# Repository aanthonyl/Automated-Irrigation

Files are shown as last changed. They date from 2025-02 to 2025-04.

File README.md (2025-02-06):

# Automated Crop Irrigation and Monitoring

This is the repository that holds the code that runs on each microcontroller.

This project focuses on creating an automated irrigation system using moisture sensors and other sensors to control a solenoid valve that controls irrigation.

## Setup
[Follow this link to initialize a new microcontroler for circuitpython](https://learn.adafruit.com/welcome-to-circuitpython/installing-circuitpython)

[More Info](https://docs.google.com/document/d/19N1eyoPY3S1OBYUITAjoR1po-gBfBbgVvcPOLOSFNLY/edit?usp=sharing)

### Libraries
[Most Libraries needed for our project](https://circuitpython.org/libraries)

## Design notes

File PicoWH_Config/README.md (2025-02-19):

This folder will contain all the configuration files necessary to recreate a new Raspberry Pi Pico WH to be compatible with this project.

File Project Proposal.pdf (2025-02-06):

# Automated Crop Irrigation and Monitoring

## AquaByte

Megan Arbuckle- Developer

Jillian Armstrong- Developer

Daniel Gruen- IoT Software & Network Engineer

Anthony Liao- Project Manager

Advisor: Carsten Thue-Bludworth, carstentb@ufl.edu

02/02/2025

## Abstract

On the Field and Fork Farm, crops are irrigated through a series of timers that

periodically send water to different fields for various set times. This system works well,

however, it is not very responsive to changes such as heavy rain, leaks, or other changes that

would need to adjust the watering schedule. Since it follows a set schedule, it can be an

inefficient usage of water since it cannot determine when it is best to water, but rather constantly

waters to make sure plants have the water they need. It also must be managed on site, so

someone must be on the farm physically to change the watering schedule or notice leaks. This

project aims to develop an automated irrigation system that leverages different sensors, including

soil moisture and sunlight intensity sensors, that are periodically measured by a microcontroller

and sent wirelessly to an online dashboard. These live readings and values will be used to

dynamically determine when plants need watering to conserve water and remove the need for a

person to manage it day to day. The online dashboard will allow a user to view the data collected

from each microcontroller and remotely manage the irrigation to turn it on or off. While other

solutions exist for this issue, our goal is to use cheaply available microcontrollers and sensors to

keep costs low for the Field and Fork Farm. Overall, this automated irrigation controller

simplifies farm management by reducing the daily workload required for irrigation, allowing

farmers to focus on other essential tasks.

## Table of Contents

Cover | 1
Abstract | 2
Table of Contents | 3
Team Contract | 4
Introduction and Motivation | 7
Literature Survey | 9
Proposed Works | 11
User Stories | 13
Project Plan | 14
Github | 16
References | 17
Advisor Signature | 18

## Team Contract

Overall objectives: What the team is trying to achieve?

- Our objective is to create an IoT system for the Field and Fork Farm that collects data on

various variables including moisture level, temperature, and light levels. Using this

information we want to be able to control irrigation schedules and be able to manage

irrigation remotely through an online dashboard.

Individual responsibilities: What each team member is expected to do?

- Communicate clearly with other members.
- Complete their portion of the work and tasks.
- Work at least three hours every week.

Values and Agreement Statements: Team agreements are written by everyone and they help

define comfortable working parameters for everyone.

- We will come to all meetings and will let each other know if a meeting time does not

work.

- We will do our work efficiently and effectively.
- We will communicate with each other about the project and about deadlines.
- We will ask for help from each other or our advisor if needed.

Software Configuration Management Protocol: refers to a set of defined procedures and

standards used to track, control, and manage changes made to the software system to ensure consistency and quality of all modifications, management of merge conflicts, and version

control.

- We are using Github for version control in our project. Due to the nature of our project,

each of us will be working with separate code bases in the same repository, so we will all

push to the main branch in separate folders that we PR to have each other look over.

Meeting times: When the team will meet outside the meeting with the advisor?

- Our team will meet weekly and the days will change depending on availability. We will

fill out a When2meet to determine the best possible day and time.

Meeting times with advisor: Frequency and Order of Meeting Facilitator (Everyone is required to

lead/facilitate at least 1 meeting with the advisor; everyone must be present for all meetings with

your advisor).

- We plan on meeting our advisor every other week during the duration of our project.

Communication: How team members will communicate with each other; what platforms?

- We will use discord/text for communicating when not meeting in person.

Conflict resolution protocol: How the team will solve problems?

- Our team will solve problems by discussing any issues with each other and working out a

solution together.

- If needed, we will discuss it with our advisor.

Consequences: What happens if someone violates the agreement?

- If someone violates the agreement, we will first try discussing the issue with a teammate

in violation of the agreement and if not resolvable, we will bring it to the attention of the

advisor and decide on the correct course of action.

Signatures

Daniel Gruen 1/18/25

Megan Arbuckle 1/18/25

Anthony Liao 1/18/25

Jillian Armstrong 1/18/25

## Introduction and Motivation

Water management in agriculture is a significant challenge, with inefficient irrigation

methods leading to water waste, increased costs, or inconsistent crop yields. Farmers must

manually monitor weather and adjust irrigation schedules, which is time-consuming and prone to

human error. Additionally, climate variability makes it difficult to predict the optimal watering

times. In the United States, agricultural irrigation accounted for 42% of the nation’s total

freshwater usage in 2015 (Dieter et al., 2018). As agricultural irrigation is a significant usage of

water, in places where water is scarce, such as California, or places where the soil is more sandy

and does not hold onto water, such as Florida, it is imperative that water is managed carefully.

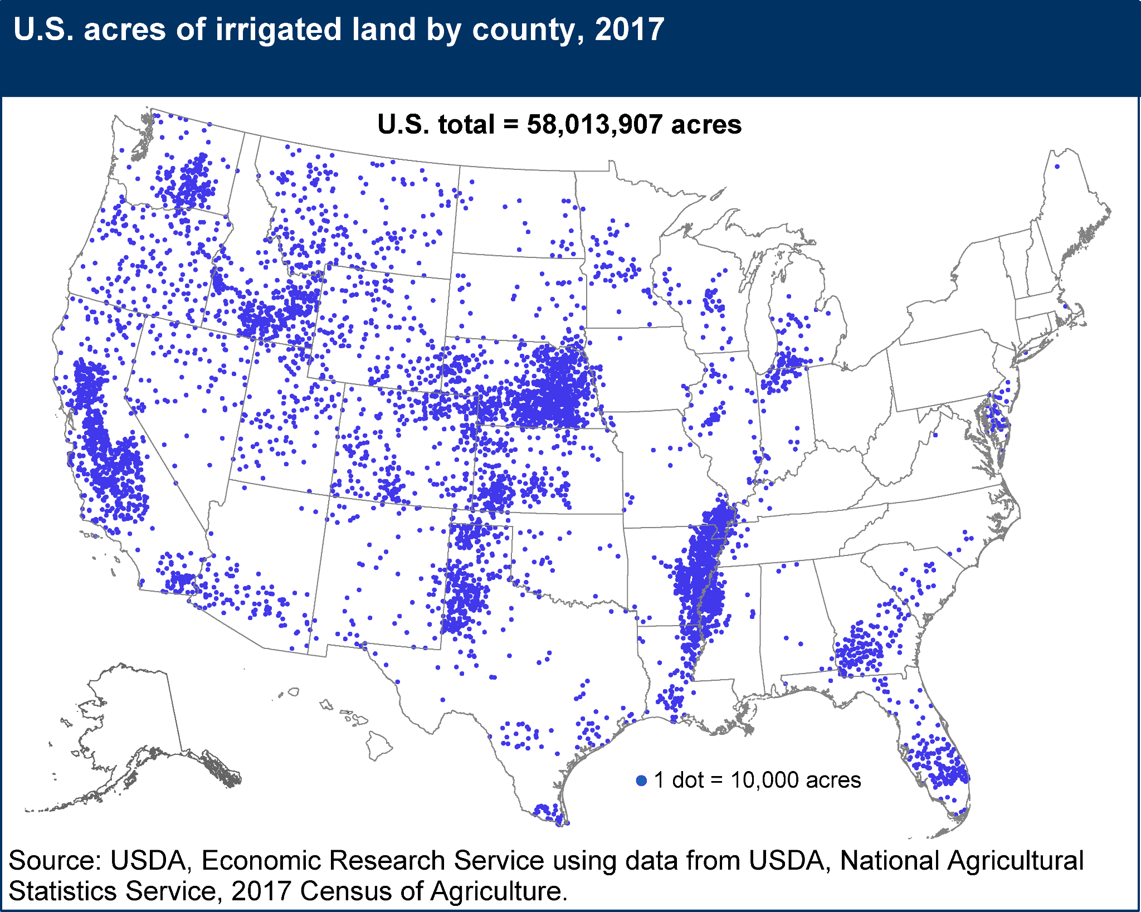
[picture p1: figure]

To help manage water usage on irrigated agricultural land, our project proposes creating

smart systems that optimize water usage by leveraging technology such as soil moisture sensors,

weather data, and automated valves to ensure crops receive the right amount of water at the right

time. This not only conserves water but also reduces labor costs and improves crop health. With many low cost sensors and microcontrollers readily available in the market, creating a scalable

and affordable system is very feasible.

Our project focuses on the Field and Fork Farm at the University of Florida, which

currently uses traditional irrigation systems which utilize timers to control watering schedules.

We propose an intelligent, sensor-based irrigation system that automatically adjusts water

distribution based on real-time environmental conditions. This will be accomplished by utilizing

moisture, light, and temperature sensors to monitor the environment, and a microcontroller to

utilize this data and control irrigation via solenoids. This microcontroller will communicate with

an online dashboard as well for ease of access to control irrigation and monitor data. The impact

of this project will be in water conservation, simplified farm management, and improving

watering consistency leading to better crop yield. By streamlining irrigation management, a

farmer’s time and energy can go into other aspects of the farm.

## Literature Survey

Literature Survey 1:

The first piece of research we found discusses the importance of soil moisture on

irrigation and the yield of crops, and how soil moisture sensor technology can help agricultural

performance (Limin Yu, et al.). The researchers discuss how they analyzed and compared

different measurement methods and how these sensors can be improved for future development.

They were able to test different kinds of moisture sensors and report the main advantages and

takeaways of how each one performed. During their testing, they determined that different

environmental factors, such as temperature, affected the measurements of the soil moisture

sensors, which is similar to what we will be testing and measuring. While our project will be on a

much smaller scale, it can also be used to determine more about the improvement of soil

moisture sensors and how they can be used in larger scale applications.

Literature Survey 2:

This idea was also carried out on farms in Indonesia by some researchers from the

Institute of Informatics and Computing Energy at Universiti Tenaga Nasional, the University

Hassan II of Casablanca, and the Department of Electrical Engineering at Gujarat Technological

University (Ipin Prasojo, et al.). They aimed to improve the efficiency of the farms because the

farmers didn’t often grow anything in dry seasons due to concerns about watering issues. In their

research, they designed a microcontroller chip that uses a moisture sensor in the soil to determine

whether the crops should be watered at a given time. The microchip would activate a solenoid

when water was needed in the soil, and would release a different amount of water depending on

how much moisture is already in the soil. It was found to be beneficial to the crop growth on the farms it was tested on, since the farmers did not have to water the soil themselves and the plants

didn’t suffer due to either over- or under-watering.

Literature Survey 3:

A research team from the G.M. Vedak Institute of Technology in India (Yadav et al.,

2021) developed a smart irrigation system to aid small and large scale farming operations alike.

It aimed to make the system more efficient and automated. They achieved this by using a variety

of sensors, such as light, moisture, and water level that takes rain into account). They integrated

these sensors using arduino controls. The project uses an Arduino microcontroller (ATmega328

microcontroller, specifically) that periodically reads the soil moisture levels, temperature and

sunlight intensity, rain sensors, along with water levels in the water tank, to calculate a logical

decision on turning on or off the irrigation system. Based on the different regions it picks up

readings from, it can decide to turn on the water pump and only open certain solenoid valves to

make sure water flows to the areas that need it, not the entire farm. The Arduino microcontroller

has a bluetooth module connected to it, which the mobile app pairs with, creating a wireless

connection. It synchronizes live data with the mobile app’s data which the user can then read and

send commands to the Arduino system, deciding how to control the irrigation system.

## Proposed Work

Plan of Work:

We plan on splitting our work into three section:

- Setting up a microcontroller to communicate with an online dashboard to send and

receive data

- Developing the software on the microcontroller to collect and interpret data from the

sensors, and validate the sensors through various test cases.

- Creating a circuit and software to control a solenoid connected to an irrigation valve.

Once these are done, we will integrate them together into one product, and test it on the Field and

Fork Farm connected to an irrigation valve on their raised beds. Further testing will be done on a

larger field with crops on them. We will be working closely with the Field and Fork Farm

manager, Noah Long, to get feedback and information.

Target Audience:

Agricultural or gardening organizations who don’t have an automated irrigation system or

have a sub-par embedded automated irrigation system aiming to achieve a viable, cost-effective,

and efficient solution to managing their irrigation system to save on water, money, and labor.

Technologies:

Sensors:

➔ EK1940 Capacitive Soil Moisture Sensor

➔ DS18B20 Temperature Probe Sensor

➔ BH1750FVI Light Intensity Sensor

Each of these are analog sensors that can be read using a microcontroller. There are many

libraries that support all of these sensors. As cost efficiency is part of our goal, we will be testing

various sensors as they can vary by manufacturer.

Microcontroller:

➔ Raspberry Pi Pico WH: Allows for more advanced networking and real-time processing

◆ Configured using CircuitPython

◆ Will be used as controller to collect data from various sensors and manage logic

that controls irrigation

◆ All data will be sent to the web server

◆ MQTT protocol will be used to communicate with the Pi Pico WH and a

subsequent web server

Web Server:

➔ A Flask web server with MQTT will be used to communicate with the Pi Pico WH.

➔ Workflow:

◆ Pi Pico WH collects and sends data via MQTT.

◆ A Flask-MQTT web server syncs with the microcontroller and receives the data.

◆ The web server will have a dashboard showing the live data and either an API or

logical button to send commands back to the microcontroller using MQTT.

◆ The Pi Pico WH listens for these commands and responds accordingly.

➔ Front-End: Display sensor data on a dashboard and send commands to microcontroller

◆ HTML, CSS, JavaScript

➔ Back-End: Host the Webpage, handle MQTT communication, and API endpoints

◆ Python: Flask, Flask-MQTT

## User Stories

As a farmer, I want to avoid giving my crops too little or too much water, to keep them as

healthy as possible.

As a farmer, I want a system that waters the crops automatically, so that I do not have to spend

time doing it.

As a maintenance person, I want the moisture measurement to record/reflect accurate

information, so that it works as intended.

As a maintenance person, I want the system to be uncompromised by typical weather conditions,

so that it works the majority of the time without issue.

As a maintenance person, I want to be able to access the soil moisture information remotely, so

that I can conduct my work/analysis anywhere.

## Project Plan

Phase 1: Microcontroller Setup and Online Dashboard Communication Goal: Use microcontrollers to start prototyping each component of the overall system and connect to sensors.
Key Milestones:
- Set up Raspberry Pi Pico WH to communicate with an online dashboard from campus
- Set up microcontrollers with various sensors and test to see that they receive valid data
- Set up microcontrollers to control solenoids
Completion Date: February 16, 2025

Presentation 1
Create a presentation that overviews the software and hardware components, and updates the current progress of the project.
Completion Date: February 23, 2025

Phase 2: Sensor Data Collection and Validation
Goal: With the prototyped microcontrollers, fully flesh them out and test them to make sure the system is robust.
Key Milestones:
- Validate communicate between Pi Pico WH and online dashboard
- (Stretch) Move from third party dashboard towards creating our own webserver to handle the data
- Validate sensors and solenoids to make sure they are consistent and reliable
- Begin creating a framework that encompasses all parts to start integration
Completion Date: March 23, 2025

Presentation 2
Create a presentation that updates the current progress of the project and addresses what is to be done and current issues.
Completion Date: March 30, 2025

Phase 3: Integration and Field Testing
Goal: Fully integrate all parts into one microcontroller and test on the Field and Fork Farm. Key Milestones:
- Integrate sensors, solenoids, and web communication.

- Test and validate on the Field and Fork Farm first on inconsequential spots, then on raised beds, then in fields.
Completion Date: April 13, 2025

Final Deliverables
Fully Integrated Automated Irrigation System
- Working irrigation system with sensors, solenoid control, and dashboard interface, running deployed on the Field and Fork Farm.
Final Report and Presentation
Completion Date: April 20, 2025

Senior Showcase 4/22

## Github

Our project will be managed through a monorepo that houses each of our individual sections in

various directories. The code that lives on each microcontroller will be organized in different

directories.

## https://github.com/aanthonyl/Automated-Irrigation

## References

Dieter, C. A., Maupin, M. A., Caldwell, R. R., Harris, M. A., Ivahnenko, T. I., Lovelace, J. K.,

Barber, N. L., & Linsey, K. S. (2018). Estimated use of water in the United States in 2015

(U.S. Geological Survey Circular 1441). U.S. Geological Survey.

https://doi.org/10.3133/cir1441

Prasojo, I., Maseleno, A., Tanane, O., & Shahu, N. (2020). Design of automatic watering system

based on Arduino. Journal of Robotics and Control (JRC), 1(2), 55–58.

https://doi.org/10.18196/jrc.1212.

U.S. Department of Agriculture, Economic Research Service. (2025, January 8). Irrigation &

water use.

https://www.ers.usda.gov/topics/farm-practices-management/irrigation-water-use

Yu, L. & Gao, W. (2021). Review of research progress on soil moisture sensor technology.

International Journal of Agricultural and Biological Engineering, 14(4), 32-44.

10.25165/j.ijabe.20211404.6404 (http://dx.doi.org/10.25165/j.ijabe.20211404.6404)

Yadav, D. P., Tondilkar, R. S., Patil, R. V., Patil, H. R., & Mhatre, V. A. (2021). Automated drip

irrigation system based on microcontroller. IJSRD - International Journal for Scientific

Research & Development, 9(8), 55-61.

https://www.ijsrd.com/Article.php?manuscript=IJSRDV9I80042

## Advisor Signature

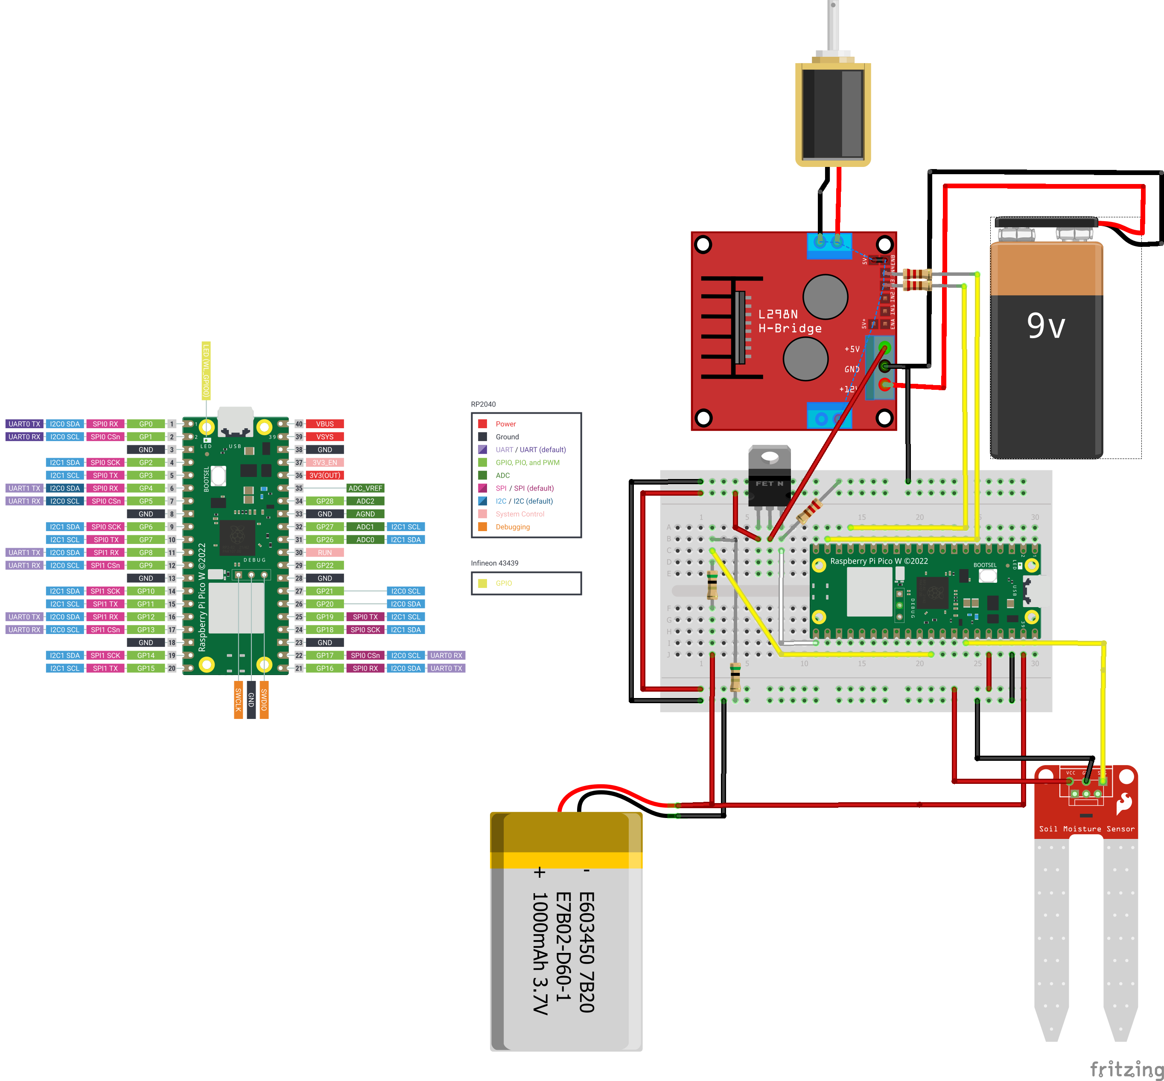
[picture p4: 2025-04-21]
Documentation/Solenoid_Controller.png

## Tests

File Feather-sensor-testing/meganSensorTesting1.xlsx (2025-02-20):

time | 1 | 2 | 3
0 | 30983 | 21125 | 20180
10 | 19892 | 21045 | 20180
20 | 20052 | 21093 | 20164
30 | 20068 | 21141 | 20164
40 | 20004 | 21157 | 20164
50 | 19940 | 21173 | 20196
60 | 19940 | 21221 | 20212
70 | 19972 | 21221 | 20180
80 | 19988 | 21253 | 20196
90 | 20020 | 21285 | 20212
100 | 20004 | 21301 | 20212
110 | 20004 | 21317 | 20244
120 | 20036 | 21333 | 20212
130 | 20052 | 21317 | 20244
140 | 20068 | 21333 | 20228
150 | 20100 | 21333 | 20212
160 | 20116 | 21381 | 20228
170 | 20116 | 21349 | 20260
180 | 20100 | 21381 | 20244
190 | 20132 | 21381 | 20244
200 | 20100 | 21381 | 20212
210 | 20132 | 21461 | 20244
220 | 20132 | 21445 | 20244
230 | 21141 | 21173 | 20276
240 | 21413 | 21189 | 20292
250 | 21573 | 21205 | 20292
260 | 21701 | 21205 | 20276
270 | 21989 | 21221 | 20228
280 | 22213 | 21221 | 20260
290 | 22405 | 21269 | 20276
300 | 22405 | 21253 | 20292
310 | 22357 | 21269 | 20308
320 | 22453 | 21285 | 20292
330 | 22341 | 21285 | 20276
340 | 22149 | 21301 | 20292
350 | 22197 | 21285 | 20324
360 | 22165 | 21317 | 20324
370 | 22165 | 21349 | 20340
380 | 19908 | 21349 | 20324
390 | 19780 | 21349 | 20340
400 | 19764 | 21349 | 20324
410 | 19716 | 21381 | 20324
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

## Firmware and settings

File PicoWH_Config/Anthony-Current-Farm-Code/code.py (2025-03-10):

import wifi
import ssl
import socketpool
import adafruit_requests
import board
import digitalio
import time
from analogio import AnalogIn
from secrets import secrets

# LED
led = digitalio.DigitalInOut(board.LED)
led.direction = digitalio.Direction.OUTPUT

# Analog Sensors
m_one = AnalogIn(board.A2)
vbat_voltage = AnalogIn(board.A0)

def get_voltage(pin):
    return (pin.value * 3.3) / 65536 * 2

# Connecting to WiFi
connected = False
while not connected:
    try:
        print("Connecting to Wi-Fi...")
        wifi.radio.connect(secrets["ssid"], secrets["password"])
        connected = True
    except:
        print("Error Connecting")
    
    time.sleep(5)

print("Connected!")
print("IP Address:", wifi.radio.ipv4_address)
print("MAC Address:", ":".join([f"{i:02X}" for i in wifi.radio.mac_address]))

# Connecting to Adafruit IO
AIO_USERNAME = secrets["ADAFRUIT_AIO_USERNAME"]
AIO_KEY = secrets["ADAFRUIT_AIO_KEY"]
FEED_NAME = "moisture"
FEED_NAME2 = "battery"

# Adafruit IO URL Construction
AIO_URL = f"https://io.adafruit.com/api/v2/{AIO_USERNAME}/feeds/{FEED_NAME}/data"
AIO_URL2 = f"https://io.adafruit.com/api/v2/{AIO_USERNAME}/feeds/{FEED_NAME2}/data"

# Socket and Requests Session
pool = socketpool.SocketPool(wifi.radio)
ssl_context = ssl.create_default_context()
requests = adafruit_requests.Session(pool, ssl_context=ssl_context)

while True:
    try:
        with open("/data.csv", "a") as temp_log:
            while True:
                # Collecting Data
                bat_volt = get_voltage(vbat_voltage)
                v1 = m_one.value

                # Logging Data to CSV file
                with open("/data.csv", "a") as log_file:
                    log_file.write('{0:.2f}, {1:.1f}\n'.format(bat_volt,v1))
                    log_file.flush()

                # Defining Data to Send
                data_moisture = {"value": (v1)}
                data_battery = {"value": (bat_volt)}
                headers = {"X-AIO-Key": AIO_KEY}

                # Sending Data to Adafruit
                print("Sending data to Adafruit IO...")
                response = requests.post(AIO_URL, json=data_moisture, headers=headers)
                response2 = requests.post(AIO_URL2, json=data_battery, headers=headers)
                # Outputting Response Code
                print("Response Code 1:", response.status_code)
                print("Response Code 2:", response2.status_code)

                time.sleep(600)

    # When the filesystem is NOT writable by CircuitPython...
    except OSError as e:
        print(f"Filesystem Error: {e}")
        # Blink the LED every 0.15 seconds if the File System is full
        if e.args[0] == 28:
            delay = 0.15
        while True:
            print(m_one.value)
            led.value = True
            time.sleep(1)
            led.value = False

    except Exception as e:
        print(f"Error: {e}")
    
    time.sleep(20)

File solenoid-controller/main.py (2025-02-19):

import board
import digitalio
import time
from analogio import AnalogIn
#from adafruit_onewire.bus import OneWireBus
#import adafruit_ds18x20

import alarm

#i2c = board.I2C()
led = digitalio.DigitalInOut(board.LED)
led.direction = digitalio.Direction.OUTPUT


p1 = digitalio.DigitalInOut(board.D10)
p2 = digitalio.DigitalInOut(board.D9)

p1.direction = digitalio.Direction.OUTPUT
p2.direction = digitalio.Direction.OUTPUT

toggle = digitalio.DigitalInOut(board.D12)
toggle.direction = digitalio.Direction.OUTPUT

once = True


vbat_voltage = AnalogIn(board.A0)
m_one = AnalogIn(board.A2)


input_pin = digitalio.DigitalInOut(board.D6)  # Replace 'D5' with your desired pin
input_pin.direction = digitalio.Direction.INPUT  # Set the pin as an input

def turn_off():
    p1.value = True 
    p2.value = False
    time.sleep(0.01)
    p1.value = False 
    p2.value = False

def turn_on():
    p1.value = False 
    p2.value = True
    time.sleep(0.01)
    p1.value = False 
    p2.value = False

def get_voltage(pin):
    return (pin.value * 3.3) / 65536 * 2

current_State = 0
value = -1
toggle.value = True
try:
    if value == -1:
        with open("/vars.txt","r") as file:
            value = file.read().strip()
            print(value)
            if value == '1':
                turn_on()
                current_State = 0
            else:
                turn_off()
                current_State = 1
        with open("/vars.txt","w") as file:
            file.write(str(current_State))

        time_alarm = alarm.time.TimeAlarm(monotonic_time=time.monotonic() + 5) #deeper sleep for 5 seconds
        alarm.exit_and_deep_sleep_until_alarms(time_alarm)


    '''
    with open("/data.csv", "a") as temp_log:
        while True:
            bat_volt = get_voltage(vbat_voltage)

            # Write the data to the data.csv file every 10 mins.
            v1 = m_one.value
            #temp_log.write('{0:.2f}, {1:.1f}, {2:.1f}, {3:.1f}, {4:.1f}\n'.format((bat_volt, light_sens.lux, ds18b20.temperature, v1, v2)))
            #temp_log.write('{0:.2f}, {1:.1f}'.format(bat_volt,v1))
            temp_log.flush()

            # deep sleep
            time_alarm = alarm.time.TimeAlarm(monotonic_time=time.monotonic() + 600) #deeper sleep for 10 mins
            alarm.exit_and_deep_sleep_until_alarms(time_alarm)
    '''

except OSError as e:  # When the filesystem is NOT writable by CircuitPython...
    delay = 0.5  # ...blink\ the LED every half second.
    if e.args[0] == 28:  # If the file system is full...
        delay = 0.15  # ...blink the LED every 0.15 seconds!
    while True:
        if once:
            #turn_on()
            print("set value!")
            once = False
            time.sleep(0.01)
        p1.value = False 
        p2.value = False
        led.value = not led.value
        print(('A0: {0:.2f}'.format(get_voltage(vbat_voltage))))
        # Read the value from the input pin
        time.sleep(delay)

'''
delay = 0.5
while True:
    print(('A0: {0:.2f}'.format(get_voltage(vbat_voltage))))
    time.sleep(delay)
    '''

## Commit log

2025-02-06 First push of code
    feather and pico code
2025-02-07 Added feather sensor testing file
2025-02-19 Solenoid control with boards
2025-02-19 Create Pico WH Folder
2025-02-20 data/graphs from testing first 3 sensors :D
    [meganSensorTesting1.xlsx]
2025-02-20 added min/max and other details
    [meganSensorTesting1.xlsx]
2025-02-21 Added sensor values, min/max and other data
    Added the first round of data values, added charts and min/max and other information
    [JillianSensorTesting1.xlsx]
2025-02-23 Add files via upload
    Configured Raspberry Pi Pico WH with CircuitPython to connect to network and communicate with Adafruit IO
2025-03-10 current running code
2025-04-21 Documentation stuff
    [Solenoid_Controller.fzz, moisture_sensor.fzz]
